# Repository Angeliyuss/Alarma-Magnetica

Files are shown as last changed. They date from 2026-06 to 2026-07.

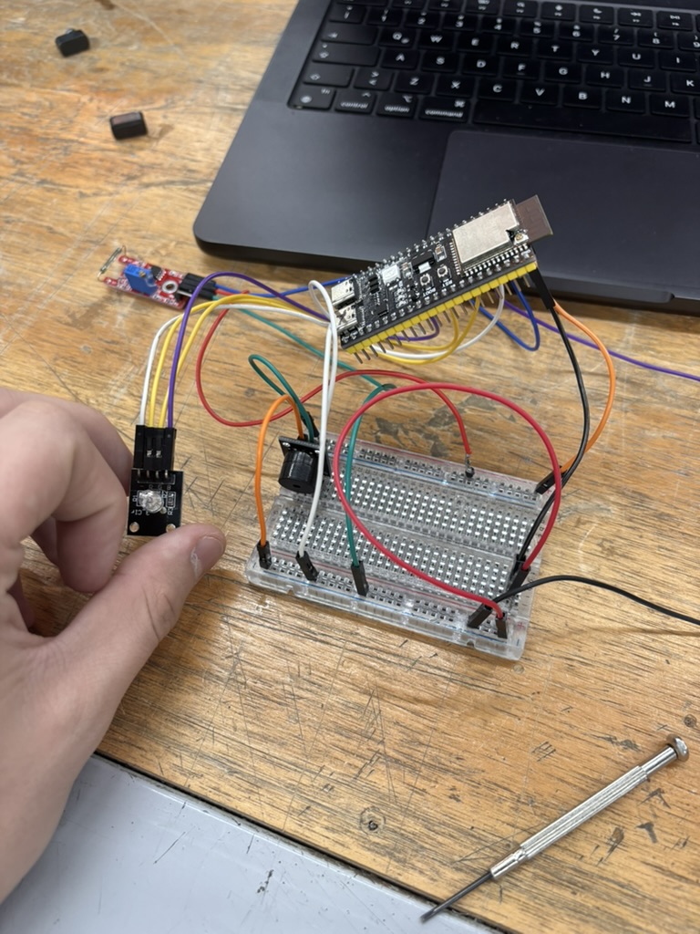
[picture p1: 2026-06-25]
hardware/fotos/FB268953-1029-4FB6-96CE-659190124670_1_105_c.jpeg

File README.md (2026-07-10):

# Sistema de Alarma Magnética Antirrobo IoT

Sistema IoT que detecta la apertura no autorizada de un acceso (puerta, cajón,
gabinete o vitrina) mediante un sensor magnético, emite una alarma sonora y visual,
y registra cada apertura con fecha y hora en la nube para su posterior análisis.

---

## Descripción

El dispositivo usa un sensor reed (KY-025) y un imán: cuando el imán se separa del
sensor (acceso abierto) estando el sistema armado, se dispara una alarma (buzzer +
LED rojo) y se registra el evento. Cada apertura se guarda de forma persistente en
Google Sheets y se visualiza en un dashboard web que muestra el historial y la hora
del día en que más se abre el acceso.

**Ciclo IoT completo:** captura (sensor) → almacenamiento (Google Sheets) →
visualización (dashboard) → información para decisiones (hora pico de aperturas).

---

## Integrantes

- Angelo Beconcini
- Sergio Contreras
- Sebastián Bustos
- Benjamín Quijada

---

## Problema que resuelve (Avance 1)

Los accesos a objetos de valor (cajones, gabinetes, vitrinas) no cuentan con un
sistema económico que avise y registre cuándo fueron abiertos. Este proyecto entrega
una alarma de bajo costo que no solo avisa en el momento, sino que **registra el
histórico de aperturas**, permitiendo identificar patrones (por ejemplo, a qué hora
del día ocurren más aperturas) para tomar decisiones de seguridad.

---

## Componentes para replicar el hardware

- ESP32-S3 N16R8
- Sensor magnético reed KY-025
- Buzzer KY-006
- LED RGB KY-016
- Switch deslizante de 3 patas
- Battery Shield 18650 + batería 18650
- Protoboard y cables dupont
- Imán

(Ver detalle de costos en `hardware/BOM.md`)

---

## Esquemático del circuito

Diagrama de conexiones completo (simulable en vivo):
**https://wokwi.com/projects/467764354317212673**

El esquemático muestra el ESP32-S3 conectado al sensor magnético (GPIO4), el buzzer
(GPIO5), el switch de armado (GPIO6) y el LED RGB (GPIO7/8/9).

---
## Autonomía y consumo energético

El sistema se alimenta con una batería Panasonic NCR18650B (3400 mAh, 3.7V)
mediante un Battery Shield que eleva el voltaje a 5V.

| Estado | Consumo aprox. | Autonomía estimada |
|---|---|---|
| Operación normal (sin alarma) | ~140 mA | ~20 horas |
| Alarma activa (buzzer + LED rojo) | ~170 mA | ~17 horas |

El cálculo considera una eficiencia del 85% en la conversión de voltaje del
Battery Shield. Como la alarma solo suena al detectar una apertura, la
autonomía real en uso normal se acerca a las 20 horas.

**Fórmula:** Autonomía = (Capacidad batería ÷ Consumo) × Eficiencia del convertidor
---

## Instrucciones de instalación

### Firmware
1. Instalar Arduino IDE y el soporte para placas ESP32 (`esp32 by Espressif`).
2. Seleccionar la placa **ESP32S3 Dev Module**.
3. Abrir `firmware/alarma_antirrobo.ino`.
4. Editar las líneas de WiFi con la red propia:
   ```cpp
   const char* ssid     = "TU_RED";
   const char* password = "TU_CLAVE";
   ```
5. Pegar la URL del Google Apps Script en la variable `URL_SHEETS`.
6. Subir el código al ESP32 con el cable USB-C.

### Repositorio de datos (Google Sheets)
1. Crear una planilla con columnas: Fecha | Hora | Timestamp.
2. En Extensiones → Apps Script, pegar el script de `firmware/google_apps_script.js`.
3. Implementar como Aplicación web con acceso "Cualquier persona".
4. Copiar la URL `/exec` y pegarla en el firmware y en el dashboard.

### Dashboard
- Versión online: **https://angeliyuss.github.io/Alarma-Magnetica/**
- O abrir `firmware/index.html` (requiere la URL del script configurada).

---

## Dashboard en vivo

**https://angeliyuss.github.io/Alarma-Magnetica/**

Muestra: aperturas de hoy, total histórico, hora más activa, última apertura,
gráfico de aperturas por hora y tabla de historial completo. Se actualiza
automáticamente cada 30 segundos.

---

## Estructura del repositorio

```
Alarma-Magnetica/
├── README.md
├── FUENTES.md
├── index.html              # Dashboard (servido por GitHub Pages)
├── firmware/
│   ├── alarma_antirrobo.ino
│   └── google_apps_script.js
├── hardware/
│   ├── BOM.md              # Lista de materiales con costos
│   └── esquematico.pdf
├── diseno-3d/
│   ├── encapsulado.f3d
│   ├── planos.pdf
│   └── renders/
├── testing/
    └── protocolo_pruebas.pdf
```

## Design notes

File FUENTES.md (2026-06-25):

# Declaración de Fuentes e Integridad Académica

Proyecto: **Sistema de Alarma Magnética Antirrobo IoT**
Asignatura: TEI201 — Taller de Diseño en Ingeniería · UAI
Avance #3 — 25 de junio de 2026

Este documento declara todas las fuentes externas, librerías y usos de inteligencia
artificial empleados en el desarrollo del proyecto, en cumplimiento del código de
honor de la Universidad Adolfo Ibáñez.

---

## 1. Librerías utilizadas

Todas las librerías son parte del core oficial de ESP32 para Arduino (no requieren
instalación externa) y son de código abierto.

| Librería | Versión | Uso en el proyecto | Fuente |
|---|---|---|---|
| WiFi.h | Core ESP32 3.x | Conexión del ESP32-S3 a la red WiFi (hotspot) en modo estación | https://github.com/espressif/arduino-esp32 |
| WebServer.h | Core ESP32 3.x | Servidor web embebido que sirve la página de registro local en la IP del ESP32 | https://github.com/espressif/arduino-esp32 |
| HTTPClient.h | Core ESP32 3.x | Envío de los registros de apertura por HTTP GET hacia Google Sheets | https://github.com/espressif/arduino-esp32 |
| time.h | C estándar / ESP32 | Obtención y formateo de la hora real vía NTP | Biblioteca estándar de C |

---

## 2. Servicios y plataformas externas

| Servicio | Uso en el proyecto | Fuente |
|---|---|---|
| Google Apps Script | Script `doGet()` que recibe los datos del ESP32 y los guarda en la planilla; también entrega los datos en formato JSON para el dashboard | https://developers.google.com/apps-script |
| Google Sheets | Repositorio de datos persistente (base de datos en la nube) donde se almacena el histórico de aperturas | https://www.google.com/sheets/about/ |
| GitHub Pages | Hosting del dashboard web público | https://pages.github.com/ |
| Servidores NTP | Sincronización de hora real (pool.ntp.org, time.google.com, time.nist.gov) | https://www.pool.ntp.org/ |

---

## 3. Código externo adaptado

No se copiaron fragmentos de código de terceros (Stack Overflow, tutoriales, repos
externos). La estructura del firmware y del dashboard fue desarrollada para este
proyecto con asistencia de IA (ver sección 4), partiendo de la documentación oficial
de las librerías listadas arriba.

---

## 4. Uso de Inteligencia Artificial

Se utilizó **Claude (Anthropic)** como herramienta de asistencia durante el
desarrollo. A continuación se declara qué generó la IA, qué hace ese código y cómo
el equipo lo comprende y adaptó.

### 4.1 Firmware del ESP32 (archivo `alarma_antirrobo.ino`)
- **Herramienta:** Claude (junio 2026)
- **Uso:** Generación de la estructura base del firmware: lectura del sensor KY-025,
  control del buzzer y LED RGB, lógica de armado/desarmado con el switch, servidor
  web y envío a Google Sheets.
- **Adaptación realizada por el equipo:**
  - Se ajustó el nivel de detección del imán (`IMAN_PRESENTE_NIVEL`) tras probar
    físicamente que el sensor entregaba la señal invertida.
  - Se ajustó la zona horaria a UTC-4 (horario de invierno de Chile) aplicando el
    offset manualmente sobre la hora UTC.
  - Se movió el envío a Google Sheets a un **segundo núcleo** del ESP32
    (`xTaskCreatePinnedToCore`) tras detectar que el envío bloqueaba la respuesta
    de la alarma. Esta fue una decisión de diseño del equipo a partir del problema
    observado en pruebas.
- **Comprensión del equipo:** Entendemos que el sensor reed (KY-025) abre/cierra un
  contacto según la presencia del imán; que el pull-up interno mantiene el pin en
  HIGH y el switch lo lleva a LOW; que el ESP32 tiene dos núcleos y por eso la tarea
  de red corre en paralelo sin congelar la alarma; y que la hora se obtiene en UTC y
  se le resta el offset de Chile para mostrarla localmente.

### 4.2 Script de Google Apps Script (`doGet`)
- **Herramienta:** Claude (junio 2026)
- **Uso:** Función que recibe los parámetros enviados por el ESP32 y agrega una fila
  a la planilla; y que, cuando se la consulta sin parámetros, devuelve todo el
  histórico en formato JSON para el dashboard.
- **Comprensión del equipo:** Entendemos que `doGet(e)` se ejecuta cuando se accede a
  la URL del script; que `e.parameter` contiene los datos de la petición; que
  `appendRow()` agrega la fila; y que la respuesta JSON es lo que lee el dashboard.

### 4.3 Dashboard web (`index.html`)
- **Herramienta:** Claude (junio 2026)
- **Uso:** Generación de la página HTML/CSS/JavaScript que lee los datos desde Google
  Sheets, calcula estadísticas (aperturas del día, total, hora pico) y dibuja el
  gráfico de barras de aperturas por hora.
- **Adaptación realizada por el equipo:** Se decidió usar la columna de *timestamp*
  como fuente de verdad para calcular fecha y hora, porque Google Sheets reinterpretó
  el texto de fecha/hora en otro formato. El cálculo de la "hora más activa" se basa
  en agrupar todos los registros por hora del día.
- **Comprensión del equipo:** Entendemos que el dashboard hace `fetch()` a la URL del
  script, recibe el JSON, recorre los registros, los agrupa por hora y genera las
  barras proporcionalmente al conteo máximo.

---

## 5. Declaración final

El equipo declara que comprende el funcionamiento de todo el código presentado,
independientemente de si fue escrito directamente o generado con asistencia de IA, y
está en condiciones de explicar cualquier función durante la evaluación.

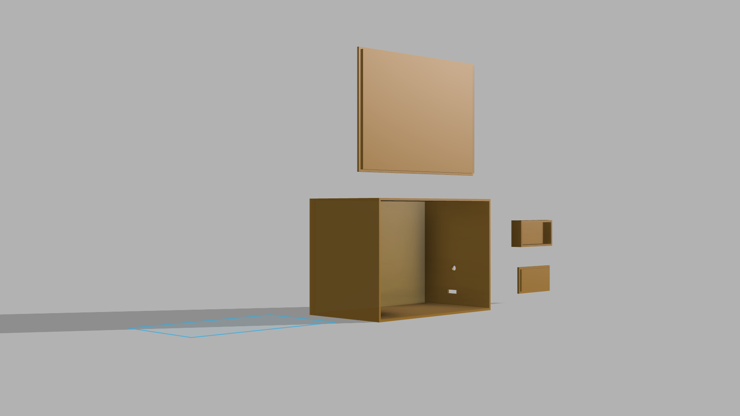
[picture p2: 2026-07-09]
Diseño 3D/DISEÑO 3D taller de diseño.png

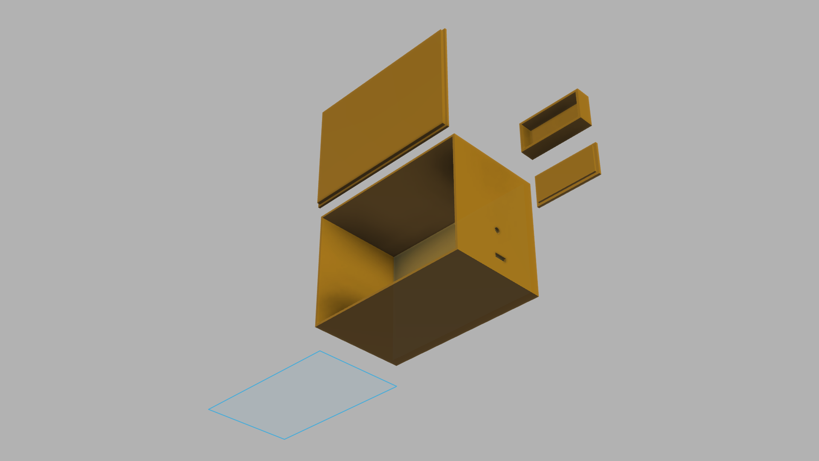
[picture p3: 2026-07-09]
Diseño 3D/DISEÑO 3D taller de diseño foto 2.png

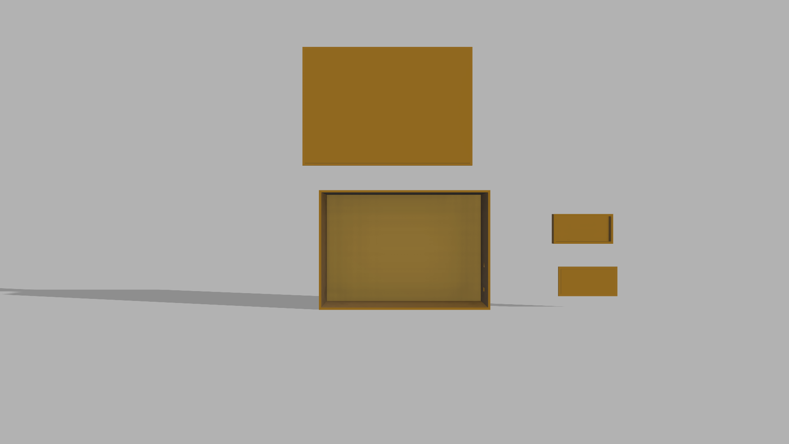
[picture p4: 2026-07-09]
Diseño 3D/DISEÑO 3D taller de diseño foto 5.png

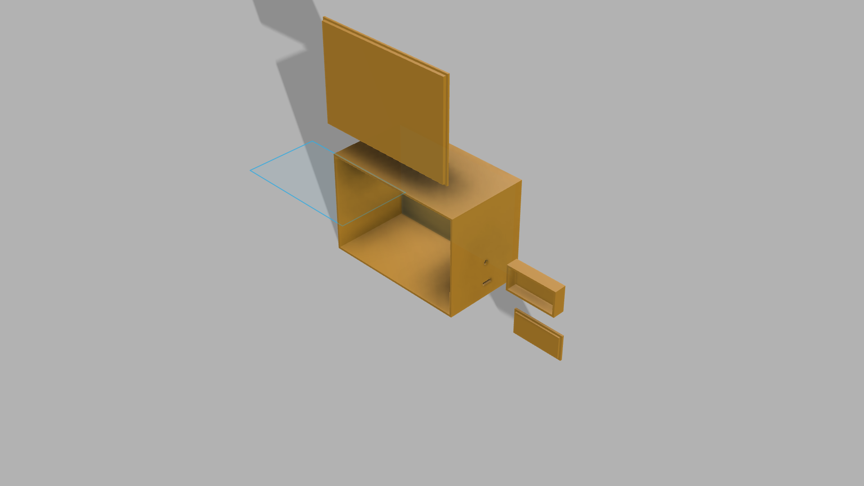
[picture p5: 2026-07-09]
Diseño 3D/DISEÑO 3D taller de diseño foto 3.png

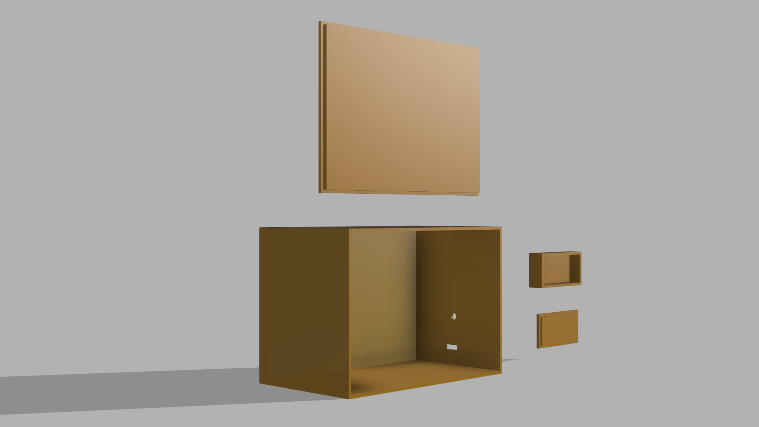
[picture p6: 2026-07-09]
Diseño 3D/DISEÑO 3D taller de diseño foto 6.png

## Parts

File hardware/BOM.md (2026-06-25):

# BOM — Lista de Materiales

**Proyecto:** Sistema de Alarma Magnética IoT
**TEI201 — Avance #3 
*Precios de referencia

| N° | Componente | Cantidad | Costo total (CLP) |
|----|---|:---:|---:|
| 1 | ESP32-S3 N16R8 | 1 | $13.000 |
| 2 | Sensor magnético KY-025 | 1 | $2.000 |
| 3 | Buzzer KY-006 | 1 | $1.200 |
| 4 | LED RGB KY-016 | 1 | $1.500 |
| 5 | Switch deslizante | 1 | $500 |
| 6 | Battery Shield 18650 | 1 | $3.500 |
| 7 | Batería 18650 | 1 | $3.000 |
| 8 | Protoboard | 1 | $2.500 |
| 9 | Set cables dupont | 1 | $2.500 |
| 10 | Imán de neodimio | 1 | $800 |
| | **COSTO TOTAL** | | **$30.500** |

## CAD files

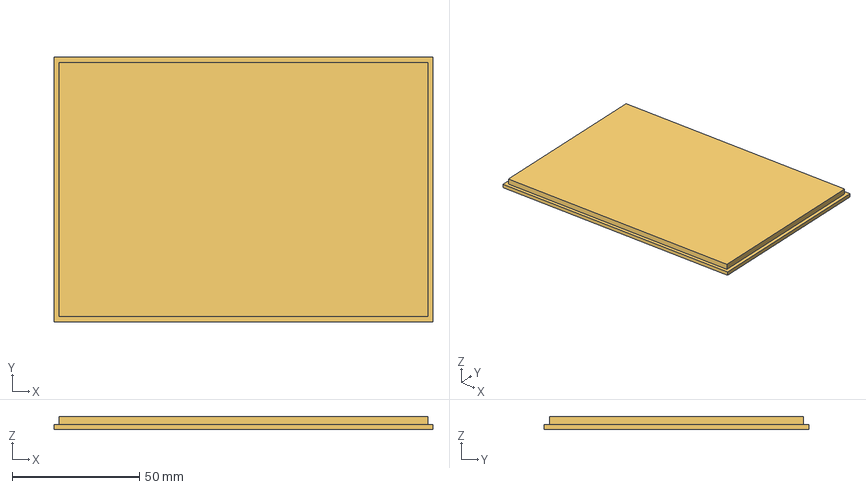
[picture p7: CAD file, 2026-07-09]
Diseño 3D/Tapa 149x104x2mm.3mf
149.0 x 104.0 x 5.00 mm

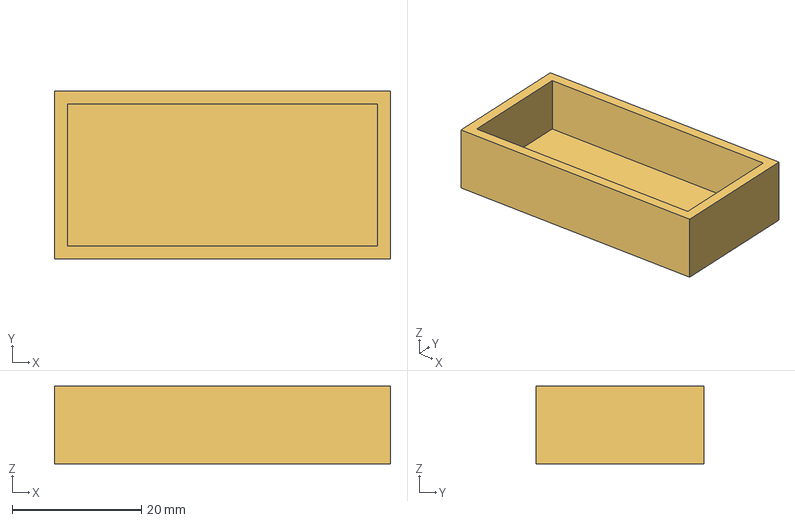
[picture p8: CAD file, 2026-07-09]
Diseño 3D/Caja_48x22x10.3mf
52.0 x 26.0 x 12.0 mm

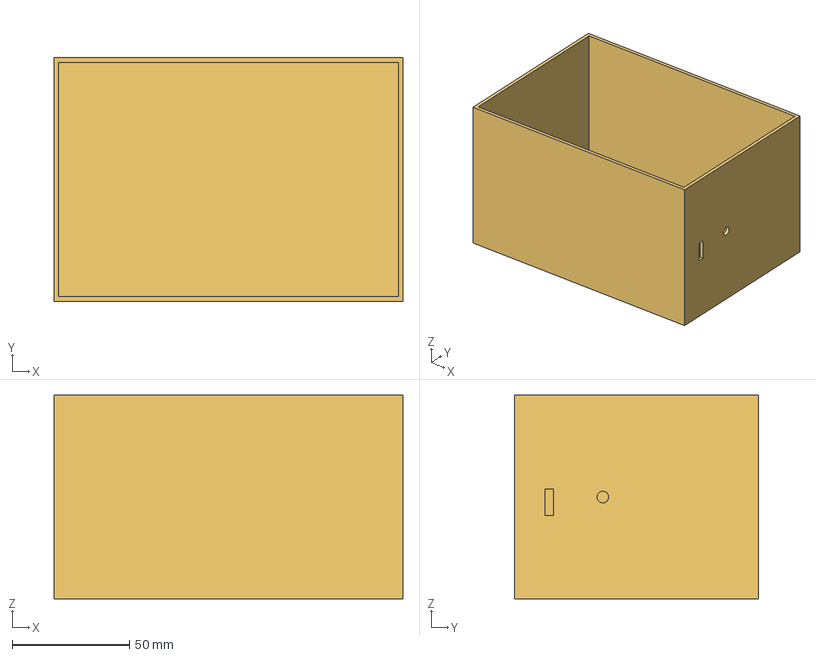
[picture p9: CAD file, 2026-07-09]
Diseño 3D/Caja interior 145x100x85mm.3mf
149.0 x 104.0 x 87.0 mm

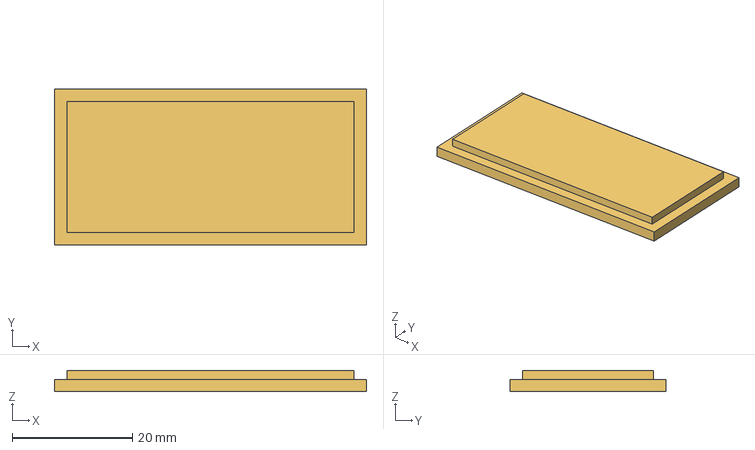
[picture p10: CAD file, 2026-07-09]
Diseño 3D/Tapa_48x22.3mf
52.0 x 26.0 x 3.50 mm

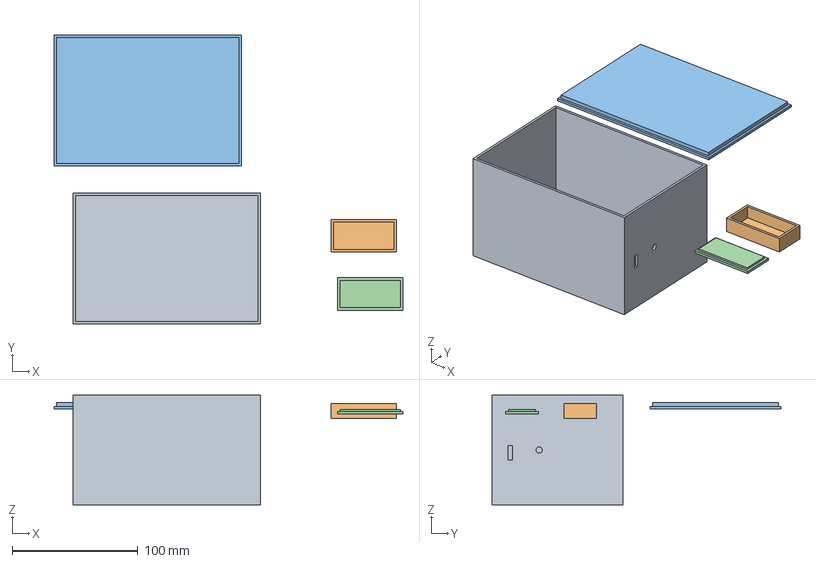
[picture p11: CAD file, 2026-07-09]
Diseño 3D/DISEÑO 3D taller de diseño.3mf
277.0 x 229.8 x 87.0 mm
Caja interior 145x100x85mm
Caja_48x22x10
Tapa 149x104x2mm
Tapa_48x22

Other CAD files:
Diseño 3D/DISEÑO 3D taller de diseño.f3d

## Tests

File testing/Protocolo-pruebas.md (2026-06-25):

# Protocolo de Pruebas y Validación

Proyecto: Sistema de Alarma Magnética Antirrobo IoT
TEI201 — Avance #3

---

## Objetivo general

Verificar que el sistema captura de forma confiable las aperturas de un acceso,
las almacena de forma persistente y las visualiza correctamente en el dashboard,
respondiendo al problema de registrar y analizar accesos no autorizados.

---

## Prueba 1 — Detección de apertura (sensor)

**Objetivo:** Verificar que el sensor detecta correctamente la separación del imán.

**Condiciones:** Sistema armado (switch en posición ON), imán en contacto con el sensor.

**Procedimiento:**
1. Armar el sistema con el switch.
2. Verificar que el LED queda en verde (acceso cerrado, imán presente).
3. Separar el imán del sensor.
4. Observar la respuesta del sistema.

**Criterio de éxito:** Al separar el imán, el LED cambia a rojo y el buzzer suena.
Al volver a acercar el imán, el buzzer se detiene y el LED vuelve a verde.

**Resultado:** Cumplido. El sistema responde de forma inmediata.

**Falla detectada y solución:** En las primeras pruebas, la lógica estaba invertida
(el buzzer sonaba con el imán presente). Se identificó que el módulo KY-025 entregaba
la señal digital invertida y se corrigió en el firmware mediante el parámetro
`IMAN_PRESENTE_NIVEL`, que permite ajustar el nivel lógico sin recablear.

---

## Prueba 2 — Sincronización de hora real (NTP)

**Objetivo:** Verificar que cada registro tiene la hora correcta de Chile.

**Condiciones:** ESP32 conectado a WiFi con acceso a internet.

**Procedimiento:**
1. Reiniciar el ESP32 y observar el Serial Monitor.
2. Verificar el mensaje "Hora sincronizada (Chile)".
3. Comparar con la hora real del momento.

**Criterio de éxito:** La hora mostrada coincide con la hora local de Santiago (UTC-4).

**Resultado:** Cumplido tras corrección.

**Falla detectada y solución:** Inicialmente la hora aparecía adelantada y, en otros
intentos, el ESP no lograba sincronizar (se quedaba en "Sincronizando hora..."). Se
detectó que (a) el offset debía aplicarse manualmente sobre UTC para evitar un doble
ajuste, y (b) el hotspot perdía internet intermitentemente. Se agregaron tres
servidores NTP de respaldo y se aplicó el offset de Chile (UTC-4) de forma manual.

---

## Prueba 3 — Almacenamiento persistente (Google Sheets)

**Objetivo:** Verificar que cada apertura se guarda en la nube y persiste tras apagar.

**Condiciones:** Sistema armado, conexión a internet activa.

**Procedimiento:**
1. Generar varias aperturas separando el imán.
2. Verificar en el Serial Monitor el mensaje "Enviado a Sheets, codigo HTTP: 200".
3. Abrir la planilla de Google Sheets y confirmar las filas nuevas.
4. Apagar y reiniciar el ESP32; volver a abrir la planilla.

**Criterio de éxito:** Cada apertura genera una fila con fecha, hora y timestamp;
los datos permanecen tras reiniciar el dispositivo.

**Resultado:** Cumplido. Los datos persisten en la nube.

**Falla detectada y solución:** Al registrar aperturas, la alarma se congelaba 2-3
segundos porque el envío a Google bloqueaba el programa. Se resolvió moviendo el
envío a Google Sheets al **segundo núcleo del ESP32** (procesamiento en paralelo), de
modo que la alarma responde al instante mientras los datos se envían en segundo plano.
Adicionalmente, se observaron errores HTTP -11 cuando el hotspot perdía señal; se
confirmó que al recuperar la conexión los envíos vuelven a completarse con código 200.

---

## Prueba 4 — Visualización en dashboard

**Objetivo:** Verificar que el dashboard muestra los datos y genera información útil.

**Condiciones:** Dashboard publicado en GitHub Pages, con datos en la planilla.

**Procedimiento:**
1. Abrir el dashboard (https://angeliyuss.github.io/Alarma-Magnetica/).
2. Verificar las tarjetas de estadísticas y el gráfico por hora.
3. Generar una apertura nueva y esperar la actualización automática (30 s).

**Criterio de éxito:** El dashboard muestra el histórico, identifica la hora con más
aperturas y se actualiza con los datos nuevos.

**Resultado:** Cumplido.

---

## Análisis de resultados (cuantitativo)

- **Tasa de detección:** 100% de las aperturas (con duración mayor a ~1 segundo)
  fueron detectadas y registradas correctamente.
- **Latencia de respuesta de la alarma:** inmediata (< 0,1 s) tras mover el envío de
  datos al segundo núcleo.
- **Limitación identificada:** aperturas extremadamente rápidas (separar y juntar el
  imán en menos de ~1 segundo, dos veces seguidas) pueden contarse como una sola. Se
  evaluó y se determinó que no es relevante para el caso de uso real, ya que una
  apertura real de un acceso dura más que ese umbral.
- **Confiabilidad de envío:** los envíos fallan (HTTP -11) solo cuando el hotspot
  pierde internet; con conexión estable la tasa de éxito es de código 200.

---

## Validación contra el problema original

El problema planteado es registrar y analizar las aperturas de un acceso para detectar
patrones de uso no autorizado. El sistema cumple este objetivo: durante las pruebas se
acumularon más de 50 registros reales en la planilla, y el dashboard identificó
automáticamente la franja horaria con mayor número de aperturas. Esto demuestra que el
dispositivo no solo avisa en el momento (alarma), sino que **genera información
accionable** (la hora pico de aperturas), permitiendo a un usuario tomar decisiones de
seguridad sobre cuándo reforzar la vigilancia del acceso.

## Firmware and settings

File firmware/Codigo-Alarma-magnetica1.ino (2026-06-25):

/* ============================================================================
   SISTEMA DE ALARMA MAGNÉTICA ANTIRROBO IoT
   TEI201 - Taller de Diseño en Ingeniería - UAI - Avance #3
   ----------------------------------------------------------------------------
   Microcontrolador: ESP32-S3 N16R8

   Qué hace:
   - Detecta la apertura de un acceso mediante un sensor magnético (reed KY-025).
   - Si el sistema está armado y se aleja el imán, dispara una alarma (buzzer
     + LED rojo) y registra el evento con fecha y hora real.
   - Cada apertura se guarda de forma persistente en Google Sheets (nube).
   - Sirve una página web local con el historial de aperturas.

   Detalle clave: el envío a Google Sheets se ejecuta en el SEGUNDO NÚCLEO del
   ESP32, para que la alarma reaccione al instante y no se congele mientras
   se comunica con internet.
   ========================================================================== */

#include <WiFi.h>         // Conexión WiFi
#include <WebServer.h>    // Servidor web embebido (página local)
#include <HTTPClient.h>   // Cliente HTTP para enviar datos a Google Sheets
#include <time.h>         // Manejo de hora real (NTP)

// ---------- PINES (conexión física de cada componente al ESP32) ----------
#define PIN_SENSOR  4   // Salida digital (DO) del sensor magnético KY-025
#define PIN_BUZZER  5   // Señal del buzzer KY-006
#define PIN_SWITCH  6   // Switch de armar / desarmar el sistema
#define PIN_LED_R   7   // Canal rojo del LED RGB
#define PIN_LED_G   8   // Canal verde del LED RGB
#define PIN_LED_B   9   // Canal azul del LED RGB

// El sensor puede entregar la señal invertida según el módulo. Este parámetro
// permite ajustar a qué nivel lógico se considera "imán presente" sin recablear.
#define IMAN_PRESENTE_NIVEL  HIGH

// ---------- Credenciales de la red WiFi ----------
const char* ssid     = "iPhone Angeliyu";
const char* password = "21012101Ca";

// ---------- URL del Google Apps Script (backend de la planilla) ----------
const char* URL_SHEETS = "https://script.google.com/macros/s/AKfycbze7cZP5LEMvWSCMegIvz0YPmM0B73EwZMt4l9lqQPetthbR3F0ZVaq6-07lGdCMdi1kQ/exec";

// Offset horario de Chile en segundos. Invierno = UTC-4. En verano cambiar a -3.
const long OFFSET_CHILE = -4 * 3600;

WebServer server(80);   // Servidor web en el puerto 80

// ---------- Almacenamiento local de eventos ----------
const int MAX_EVENTOS = 200;        // Capacidad máxima de registros en memoria
time_t eventos[MAX_EVENTOS];        // Arreglo con la hora (timestamp) de cada apertura
int totalEventos = 0;               // Cantidad de aperturas registradas
bool alarmaPrevia = false;          // Evita registrar la misma apertura varias veces

// ---------- Variables compartidas con el segundo núcleo ----------
// 'volatile' indica que pueden cambiar desde otra tarea/núcleo en cualquier momento.
volatile time_t colaEnvio = 0;          // Evento pendiente de enviar a Sheets
volatile bool hayEnvioPendiente = false; // Indica si hay algo por enviar

// Enciende el LED RGB con la combinación de colores indicada (1 = encendido).
void setLED(bool r, bool g, bool b) {
  digitalWrite(PIN_LED_R, r);
  digitalWrite(PIN_LED_G, g);
  digitalWrite(PIN_LED_B, b);
}

// Convierte un timestamp UTC a la fecha local de Chile (dd/mm/aaaa).
String soloFecha(time_t t) {
  time_t local = t + OFFSET_CHILE;   // Aplica el offset de Chile
  struct tm tm_info;
  gmtime_r(&local, &tm_info);        // gmtime para NO volver a aplicar zona horaria
  char buf[20];
  strftime(buf, sizeof(buf), "%d/%m/%Y", &tm_info);
  return String(buf);
}

// Convierte un timestamp UTC a la hora local de Chile (HH:MM:SS).
String soloHora(time_t t) {
  time_t local = t + OFFSET_CHILE;
  struct tm tm_info;
  gmtime_r(&local, &tm_info);
  char buf[20];
  strftime(buf, sizeof(buf), "%H:%M:%S", &tm_info);
  return String(buf);
}

// Devuelve fecha y hora juntas, para mostrar en la página web.
String formatearHora(time_t t) {
  return soloFecha(t) + "  " + soloHora(t);
}

/* ---- TAREA DEL SEGUNDO NÚCLEO ----
   Corre en paralelo a la alarma. Revisa si hay un evento pendiente y, si hay
   conexión WiFi, lo envía a Google Sheets. Así la comunicación con internet
   nunca bloquea la detección de la alarma. */
void tareaSheets(void* parametro) {
  for (;;) {   // Bucle infinito propio de esta tarea
    if (hayEnvioPendiente && WiFi.status() == WL_CONNECTED) {
      time_t t = colaEnvio;
      HTTPClient http;
      // Arma la URL con los datos del evento como parámetros
      String url = String(URL_SHEETS) + "?fecha=" + soloFecha(t) +
                   "&hora=" + soloHora(t) + "&timestamp=" + String((unsigned long)t);
      url.replace(" ", "%20");   // Codifica los espacios para la URL
      http.begin(url);
      http.setFollowRedirects(HTTPC_STRICT_FOLLOW_REDIRECTS); // Google redirige; hay que seguirlo
      int codigo = http.GET();   // Realiza la petición
      Serial.print("Enviado a Sheets, codigo HTTP: ");
      Serial.println(codigo);    // 200 = enviado con éxito
      http.end();
      hayEnvioPendiente = false; // Marca como enviado
    }
    vTaskDelay(100 / portTICK_PERIOD_MS); // Cede tiempo de CPU (no bloquea)
  }
}

// Registra una nueva apertura: la guarda en memoria y la deja en cola para Sheets.
void registrarEvento() {
  if (totalEventos < MAX_EVENTOS) {
    time_t ahora;
    time(&ahora);                 // Hora actual (UTC)
    eventos[totalEventos] = ahora;
    totalEventos++;
    colaEnvio = ahora;            // Deja el evento para que el otro núcleo lo envíe
    hayEnvioPendiente = true;
  }
}

// Construye y entrega la página web con la tabla de aperturas registradas.
void manejarRaiz() {
  String html = "<!DOCTYPE html><html><head><meta charset='UTF-8'>";
  html += "<meta name='viewport' content='width=device-width,initial-scale=1'>";
  html += "<meta http-equiv='refresh' content='5'>";  // Se actualiza sola cada 5 s
  html += "<title>Registro de Aperturas</title>";
  html += "<style>body{font-family:sans-serif;background:#111;color:#eee;padding:20px;}";
  html += "h1{color:#e24b4a;}table{width:100%;border-collapse:collapse;margin-top:15px;}";
  html += "th,td{border:1px solid #444;padding:10px;text-align:left;}th{background:#222;}";
  html += ".vacio{color:#888;margin-top:20px;}</style></head><body>";
  html += "<h1>Registro de Aperturas</h1>";
  html += "<p>Total de aperturas: <b>" + String(totalEventos) + "</b></p>";

  if (totalEventos == 0) {
    html += "<p class='vacio'>Sin aperturas registradas aun.</p>";
  } else {
    // Recorre los eventos del más reciente al más antiguo
    html += "<table><tr><th>#</th><th>Fecha y hora de apertura</th></tr>";
    for (int i = totalEventos - 1; i >= 0; i--) {
      html += "<tr><td>" + String(i + 1) + "</td><td>" + formatearHora(eventos[i]) + "</td></tr>";
    }
    html += "</table>";
  }
  html += "</body></html>";
  server.send(200, "text/html", html);   // Envía la página al navegador
}

void setup() {
  Serial.begin(115200);   // Inicia comunicación serial para depuración

  // Configura los pines de entrada (con resistencia pull-up interna) y salida
  pinMode(PIN_SENSOR, INPUT_PULLUP);
  pinMode(PIN_SWITCH, INPUT_PULLUP);
  pinMode(PIN_BUZZER, OUTPUT);
  pinMode(PIN_LED_R, OUTPUT);
  pinMode(PIN_LED_G, OUTPUT);
  pinMode(PIN_LED_B, OUTPUT);

  noTone(PIN_BUZZER);   // Buzzer apagado al iniciar
  setLED(1, 0, 0);      // LED en rojo al iniciar (sistema en reposo)

  // ---- Conexión a la red WiFi ----
  WiFi.begin(ssid, password);
  Serial.print("Conectando a WiFi");
  while (WiFi.status() != WL_CONNECTED) {  // Espera hasta conectar
    delay(500);
    Serial.print(".");
  }
  Serial.println();
  Serial.print("Conectado! Abre esta IP en el navegador: ");
  Serial.println(WiFi.localIP());   // Muestra la IP para acceder a la página

  // ---- Sincronización de la hora real por NTP ----
  // Se traen 3 servidores de respaldo por si alguno no responde.
  configTime(0, 0, "pool.ntp.org", "time.google.com", "time.nist.gov");

  Serial.print("Sincronizando hora");
  time_t ahora = 0;
  int intentos = 0;
  // Espera hasta tener una hora válida (o se rinde tras 30 intentos)
  while (ahora < 100000 && intentos < 30) {
    time(&ahora);
    Serial.print(".");
    delay(500);
    intentos++;
  }
  Serial.println();
  if (ahora > 100000) {
    Serial.print("Hora sincronizada (Chile): ");
    Serial.println(formatearHora(ahora));
  } else {
    Serial.println("NO se pudo sincronizar (revisa internet del hotspot)");
  }

  // ---- Inicia el servidor web ----
  server.on("/", manejarRaiz);   // Ruta principal -> muestra la tabla
  server.begin();

  // ---- Lanza la tarea de envío a Sheets en el núcleo 0 ----
  // La alarma corre en el núcleo 1; el envío a internet en el 0, en paralelo.
  xTaskCreatePinnedToCore(tareaSheets, "tareaSheets", 8192, NULL, 1, NULL, 0);
}

void loop() {
  server.handleClient();   // Atiende las peticiones a la página web

  // El sistema está armado cuando el switch conecta el pin a GND (LOW)
  bool armado = (digitalRead(PIN_SWITCH) == LOW);

  if (armado) {
    // Lee si el imán está presente (acceso cerrado) o ausente (abierto)
    bool imanPresente = (digitalRead(PIN_SENSOR) == IMAN_PRESENTE_NIVEL);

    if (imanPresente) {
      // Acceso cerrado: todo en orden
      setLED(0, 1, 0);          // Verde
      noTone(PIN_BUZZER);       // Sin sonido
      alarmaPrevia = false;
    } else {
      // Acceso abierto: ¡alarma!
      setLED(1, 0, 0);          // Rojo
      tone(PIN_BUZZER, 2000);   // Suena a 2 kHz
      if (!alarmaPrevia) {      // Registra solo una vez por apertura
        registrarEvento();
        alarmaPrevia = true;
      }
    }
  } else {
    // Sistema desarmado: todo en reposo
    noTone(PIN_BUZZER);
    setLED(1, 0, 0);            // Rojo (desarmado)
    alarmaPrevia = false;
  }

  delay(50);   // Pequeña pausa para estabilidad
}

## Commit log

2026-06-25 Rename corte MDF sn dientes.f3d to diseño para cortar
2026-06-25 Rename diseño para cortar to diseñoparacortar.f3d
    [diseñoparacortar.f3d]
